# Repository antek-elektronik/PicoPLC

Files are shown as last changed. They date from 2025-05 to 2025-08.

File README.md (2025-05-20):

# picoPLC

Work in progress! 

This is 'industriual' adaptation for raspberry pi pico 2W. This is a hobby project developed by me (AntekElektronik) with no plans for building it (yet). 

## features 

This device features a 8 optotransistor 24V inputs, 4 10A 230V relay outputs and 4 transistor outputs latching to ground. The device is powered by 24V external power supply and has 24V -> 5V switching power regulator onboard (the rpi pico 2w takes care of regulating 3.3V). 

## wireles connectivity

I am aware that rpi pico's wireless features won't work enclosed inside a metal case. I plan on changing to esp32 with external antenna in future. This project could be used as a base for mainstream microcontroller based PLC controllers

## software

for the time of writing this, I do not have any software written. First stage would be a micropython file with predefined variables and functions for basic I/O operations on picoPLC platform, the rest would have to be written in micropython. 

I plan to use an existng project like openPLC, find something similar or write from scratch a program for executing ladder logic or function blocks.

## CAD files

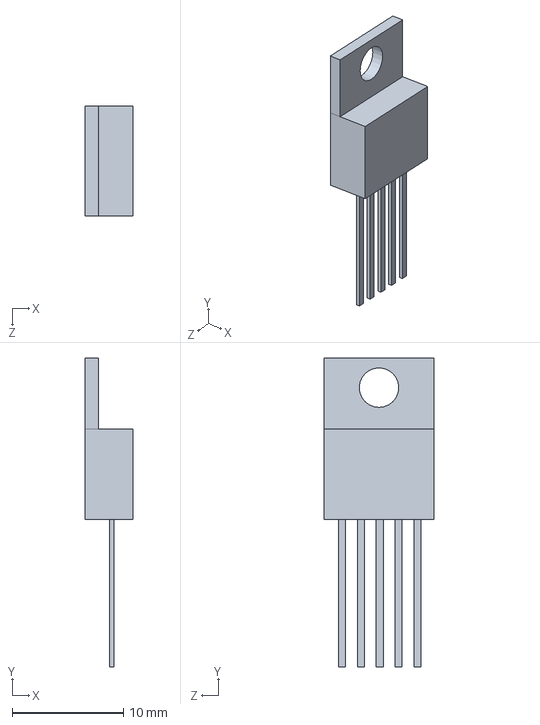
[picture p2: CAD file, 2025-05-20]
Hardware/CPU/lm 2578.SLDPRT
4.32 x 27.8 x 9.91 mm

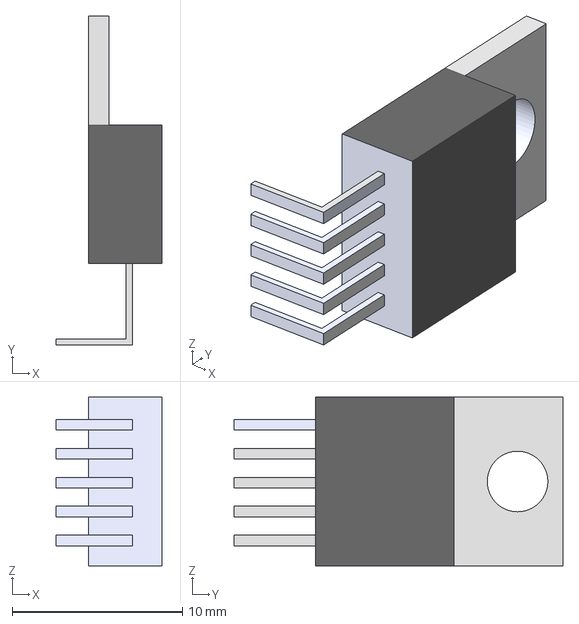
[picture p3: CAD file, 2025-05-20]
Hardware/CPU/lm 2578 - Part 1.step
6.22 x 19.3 x 9.91 mm

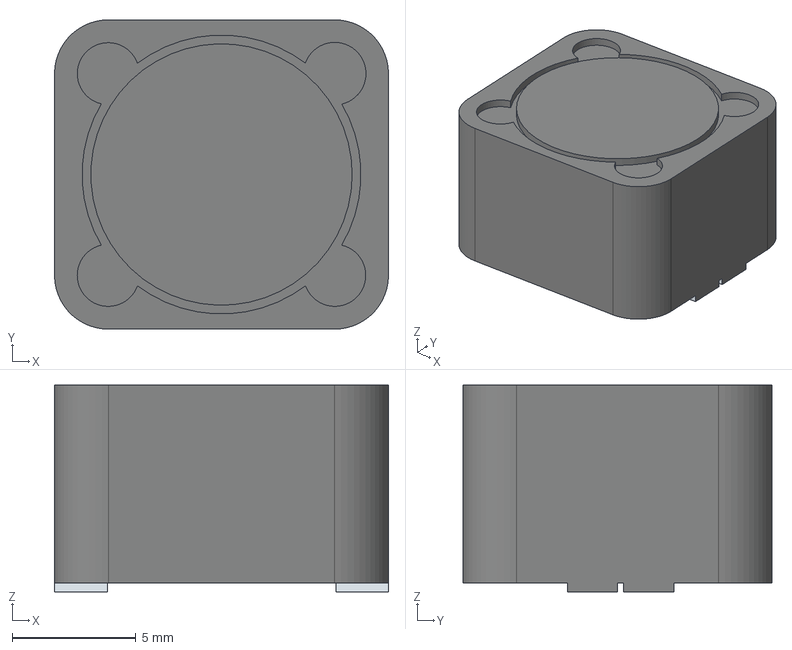
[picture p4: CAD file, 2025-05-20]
Hardware/CPU/DRQ127.step
13.5 x 12.5 x 8.36 mm

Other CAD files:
Hardware/CPU/DRQ127.sldprt
Hardware/CPU/DRQ127.stl
Hardware/CPU/lm 2578 - Part 1.iges
Hardware/CPU/lm 2578 - Part 1.sldprt
Hardware/CPU/lm 2578 - Part 1.stl
Hardware/CPU/lm 2578.stl

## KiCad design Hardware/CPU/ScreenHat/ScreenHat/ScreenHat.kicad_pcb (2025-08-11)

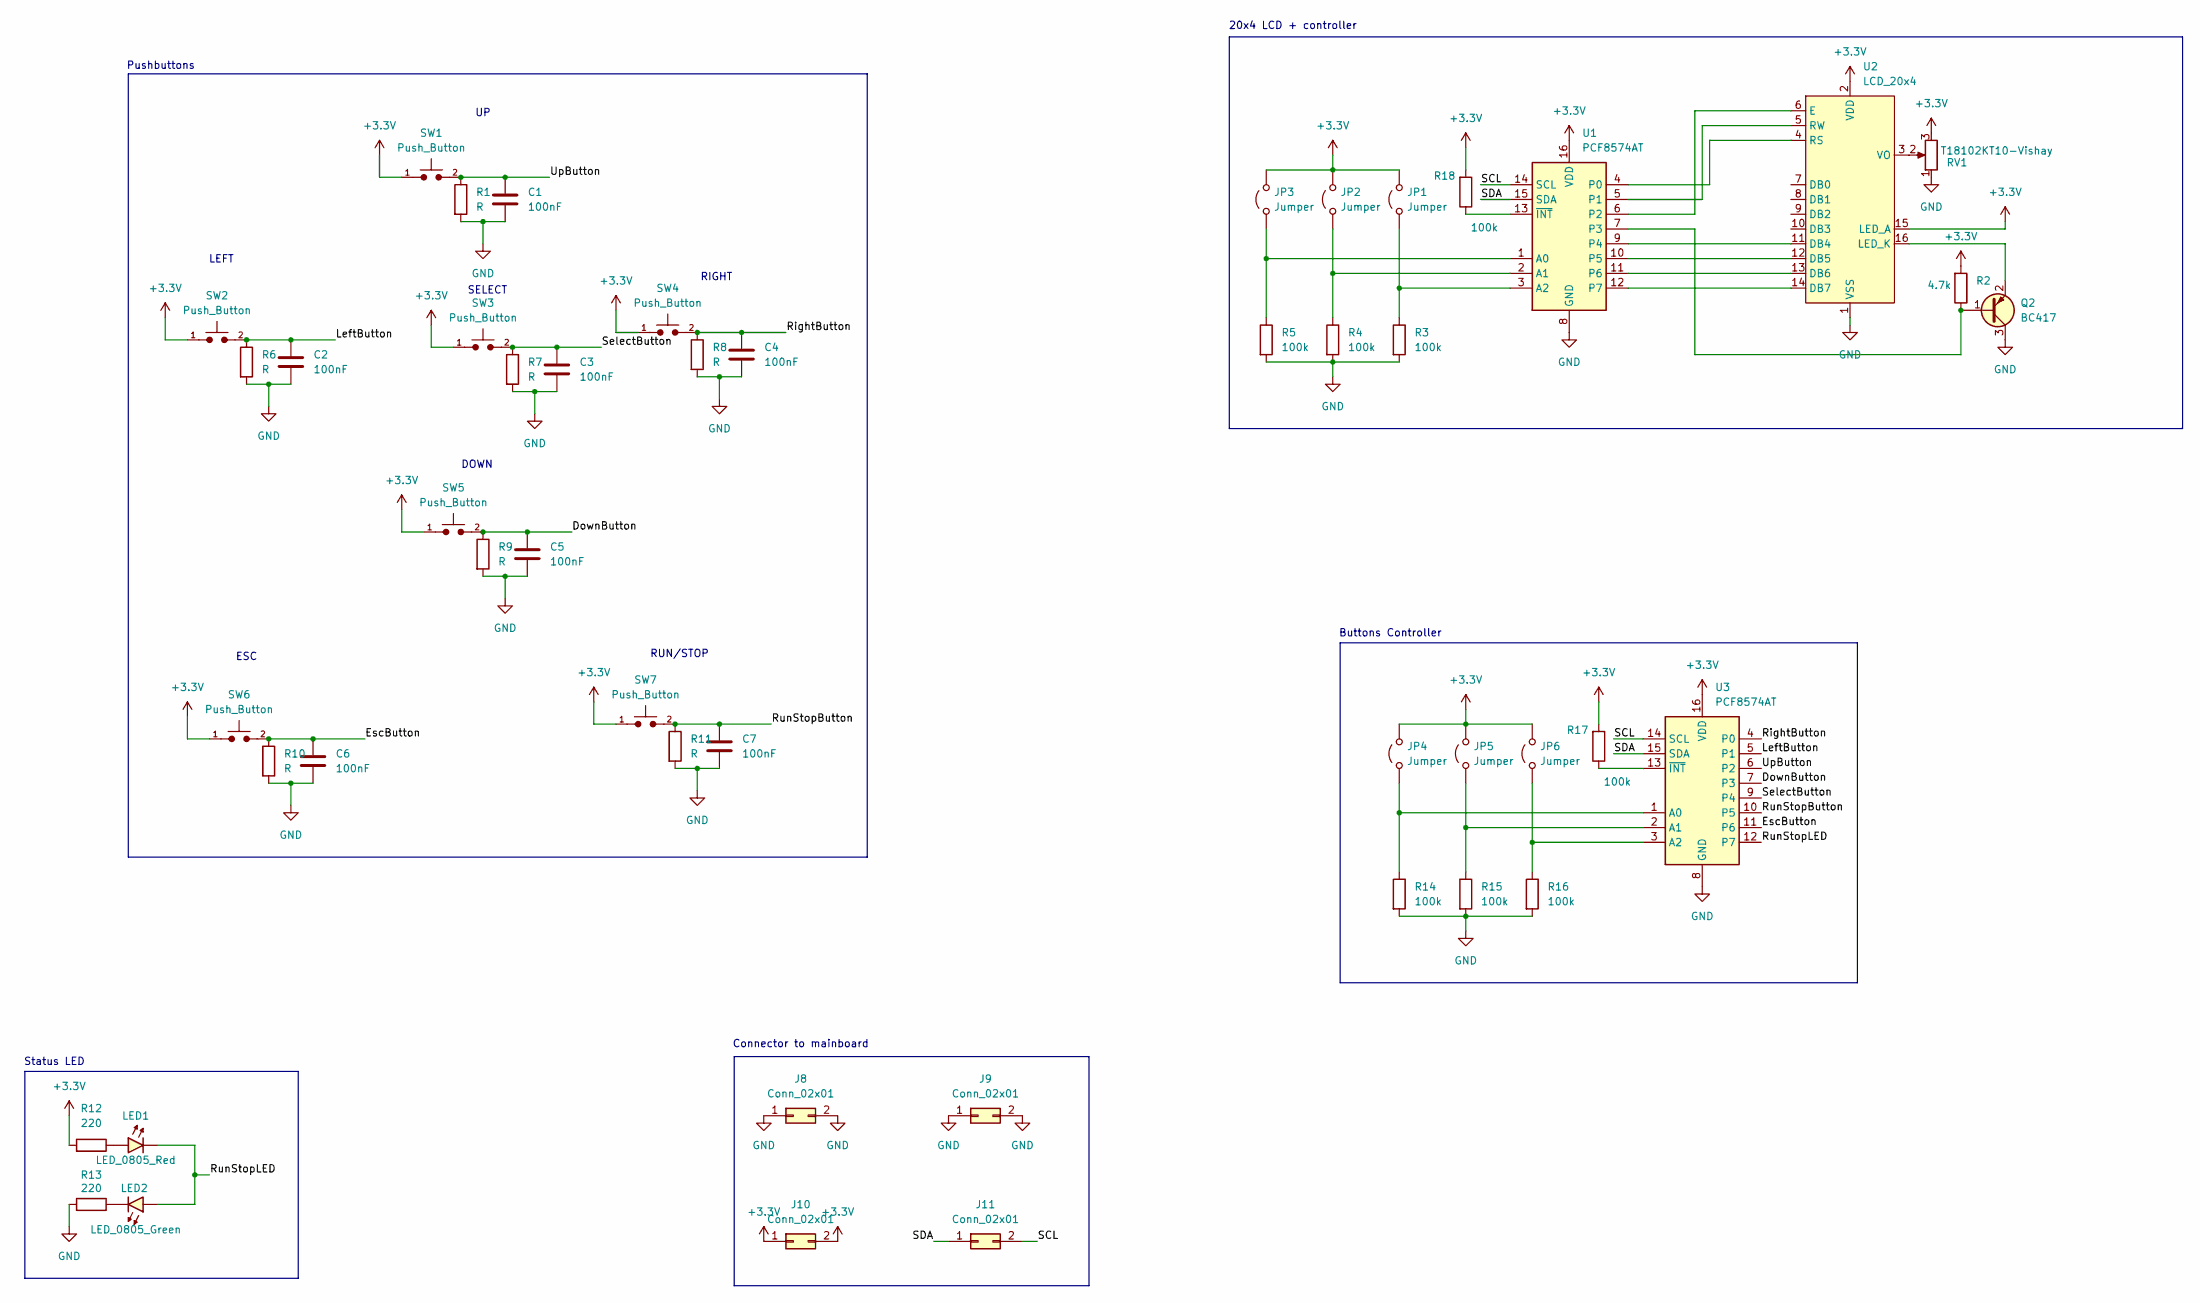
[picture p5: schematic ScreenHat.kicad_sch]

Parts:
C1, C2, C3, C4, C5, C6, C7: 100nF; C_0805_2012Metric_Pad1.18x1.45mm_HandSolder
J8, J9, J10, J11: Conn_02x01; PinHeader_2x01_P2.54mm_Vertical
JP1, JP2, JP3, JP4, JP5, JP6: Jumper; SolderJumper-2_P1.3mm_Open_RoundedPad1.0x1.5mm
LED1: LED_0805_Red; LED_0805_2012Metric
LED2: LED_0805_Green; LED_0805_2012Metric
Q2: BC417; SOT-23
R1, R6, R7, R8, R9, R10, R11: R; R_0805_2012Metric_Pad1.15x1.40mm_HandSolder
R2: 4.7k; R_0805_2012Metric
R3, R4, R5, R14, R15, R16: 100k; R_0805_2012Metric_Pad1.15x1.40mm_HandSolder
R12, R13: 220; R_0805_2012Metric
R17, R18: 100k; R_0805_2012Metric
RV1: T18102KT10-Vishay; Potentiometer_Bourns_3009P_Horizontal
SW1, SW2, SW3, SW4, SW5, SW6, SW7: Push_Button; SW_SPST_Omron_B3FS-105xP
U1, U3: PCF8574AT; SOIC-16W_7.5x10.3mm_P1.27mm
U2: LCD_20x4; LCD-16X4

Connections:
+3.3V: J10.1, J10.2, JP1.2 (B), JP2.2 (B), JP3.2 (B), JP4.2 (B), JP5.2 (B), JP6.2 (B), R2.1, R12.1, R17.1, R18.1, RV1.3, SW1.1, SW2.1, SW3.1, SW4.1, SW5.1, SW6.1, SW7.1, U1.16 (VDD), U2.2 (VDD), U2.15 (LED_A), U3.16 (VDD)
/DownButton: C5.1, R9.1, SW5.2, U3.7 (P3)
/EscButton: C6.1, R10.1, SW6.2, U3.11 (P6)
/LeftButton: C2.1, R6.1, SW2.2, U3.5 (P1)
/RightButton: C4.1, R8.1, SW4.2, U3.4 (P0)
/RunStopButton: C7.1, R11.1, SW7.2, U3.10 (P5)
/RunStopLED: LED1.1 (K), LED2.2 (A), U3.12 (P7)
/SCL: J11.2, U1.14 (SCL), U3.14 (SCL)
/SDA: J11.1, U1.15 (SDA), U3.15 (SDA)
/SelectButton: C3.1, R7.1, SW3.2, U3.9 (P4)
/UpButton: C1.1, R1.1, SW1.2, U3.6 (P2)
GND: C1.2, C2.2, C3.2, C4.2, C5.2, C6.2, C7.2, J8.1, J8.2, J9.1, J9.2, Q2.3 (C), R1.2, R3.2, R4.2, R5.2, R6.2, R7.2, R8.2, R9.2, R10.2, R11.2, R13.1, R14.2, R15.2, R16.2, RV1.1, U1.8 (GND), U2.1 (VSS), U3.8 (GND)
unnamed: JP1.1 (A), R3.1, U1.3 (A2)
unnamed: JP2.1 (A), R4.1, U1.2 (A1)
unnamed: JP3.1 (A), R5.1, U1.1 (A0)
unnamed: JP4.1 (A), R14.1, U3.1 (A0)
unnamed: JP5.1 (A), R15.1, U3.2 (A1)
unnamed: JP6.1 (A), R16.1, U3.3 (A2)
unnamed: LED1.2 (A), R12.2
unnamed: LED2.1 (K), R13.2
unnamed: Q2.1 (B), R2.2, U1.7 (P3)
unnamed: Q2.2 (E), U2.16 (LED_K)
unnamed: U1.4 (P0), U2.4 (RS)
unnamed: U1.5 (P1), U2.5 (RW)
unnamed: U1.6 (P2), U2.6 (E)
unnamed: U1.9 (P4), U2.11 (DB4)
unnamed: U1.10 (P5), U2.12 (DB5)
unnamed: U1.11 (P6), U2.13 (DB6)
unnamed: U1.12 (P7), U2.14 (DB7)
unnamed: R18.2, U1.13 (~INT)
unnamed: RV1.2, U2.3 (VO)
unnamed: R17.2, U3.13 (~INT)

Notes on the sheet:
DOWN
20x4 LCD + controller
ESC
RIGHT
Connector to mainboard
LEFT
Buttons Controller
SELECT
Pushbuttons
RUN/STOP
Status LED

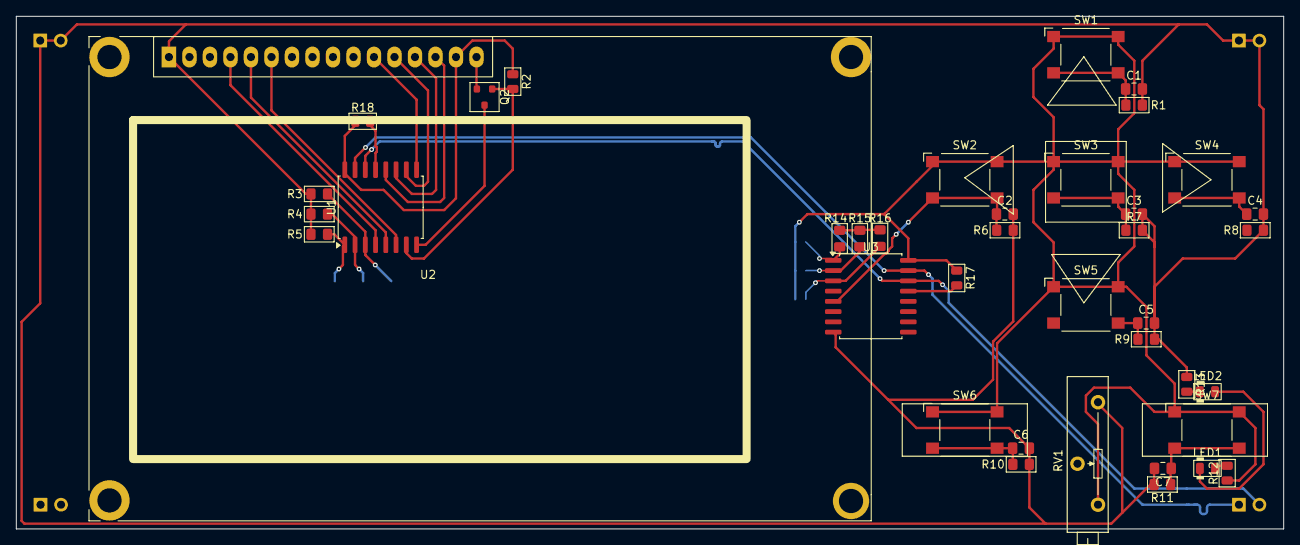
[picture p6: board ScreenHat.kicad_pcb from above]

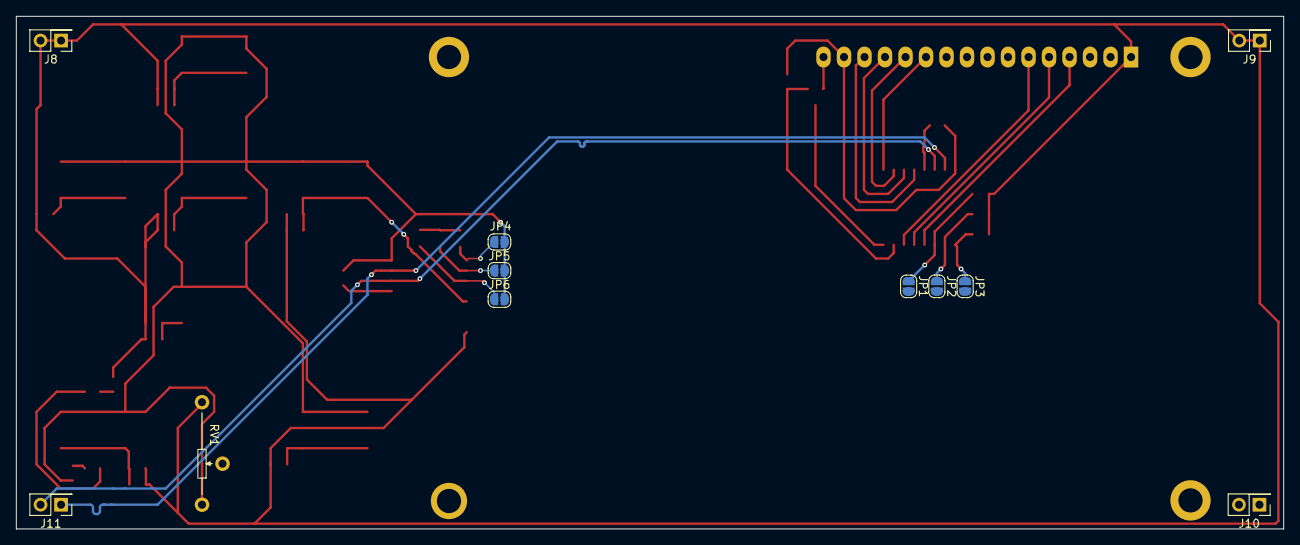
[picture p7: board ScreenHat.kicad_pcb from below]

Board: 2 copper layers, 157.0 x 63.5 mm, 49 parts (10 on the bottom side), 32 nets.

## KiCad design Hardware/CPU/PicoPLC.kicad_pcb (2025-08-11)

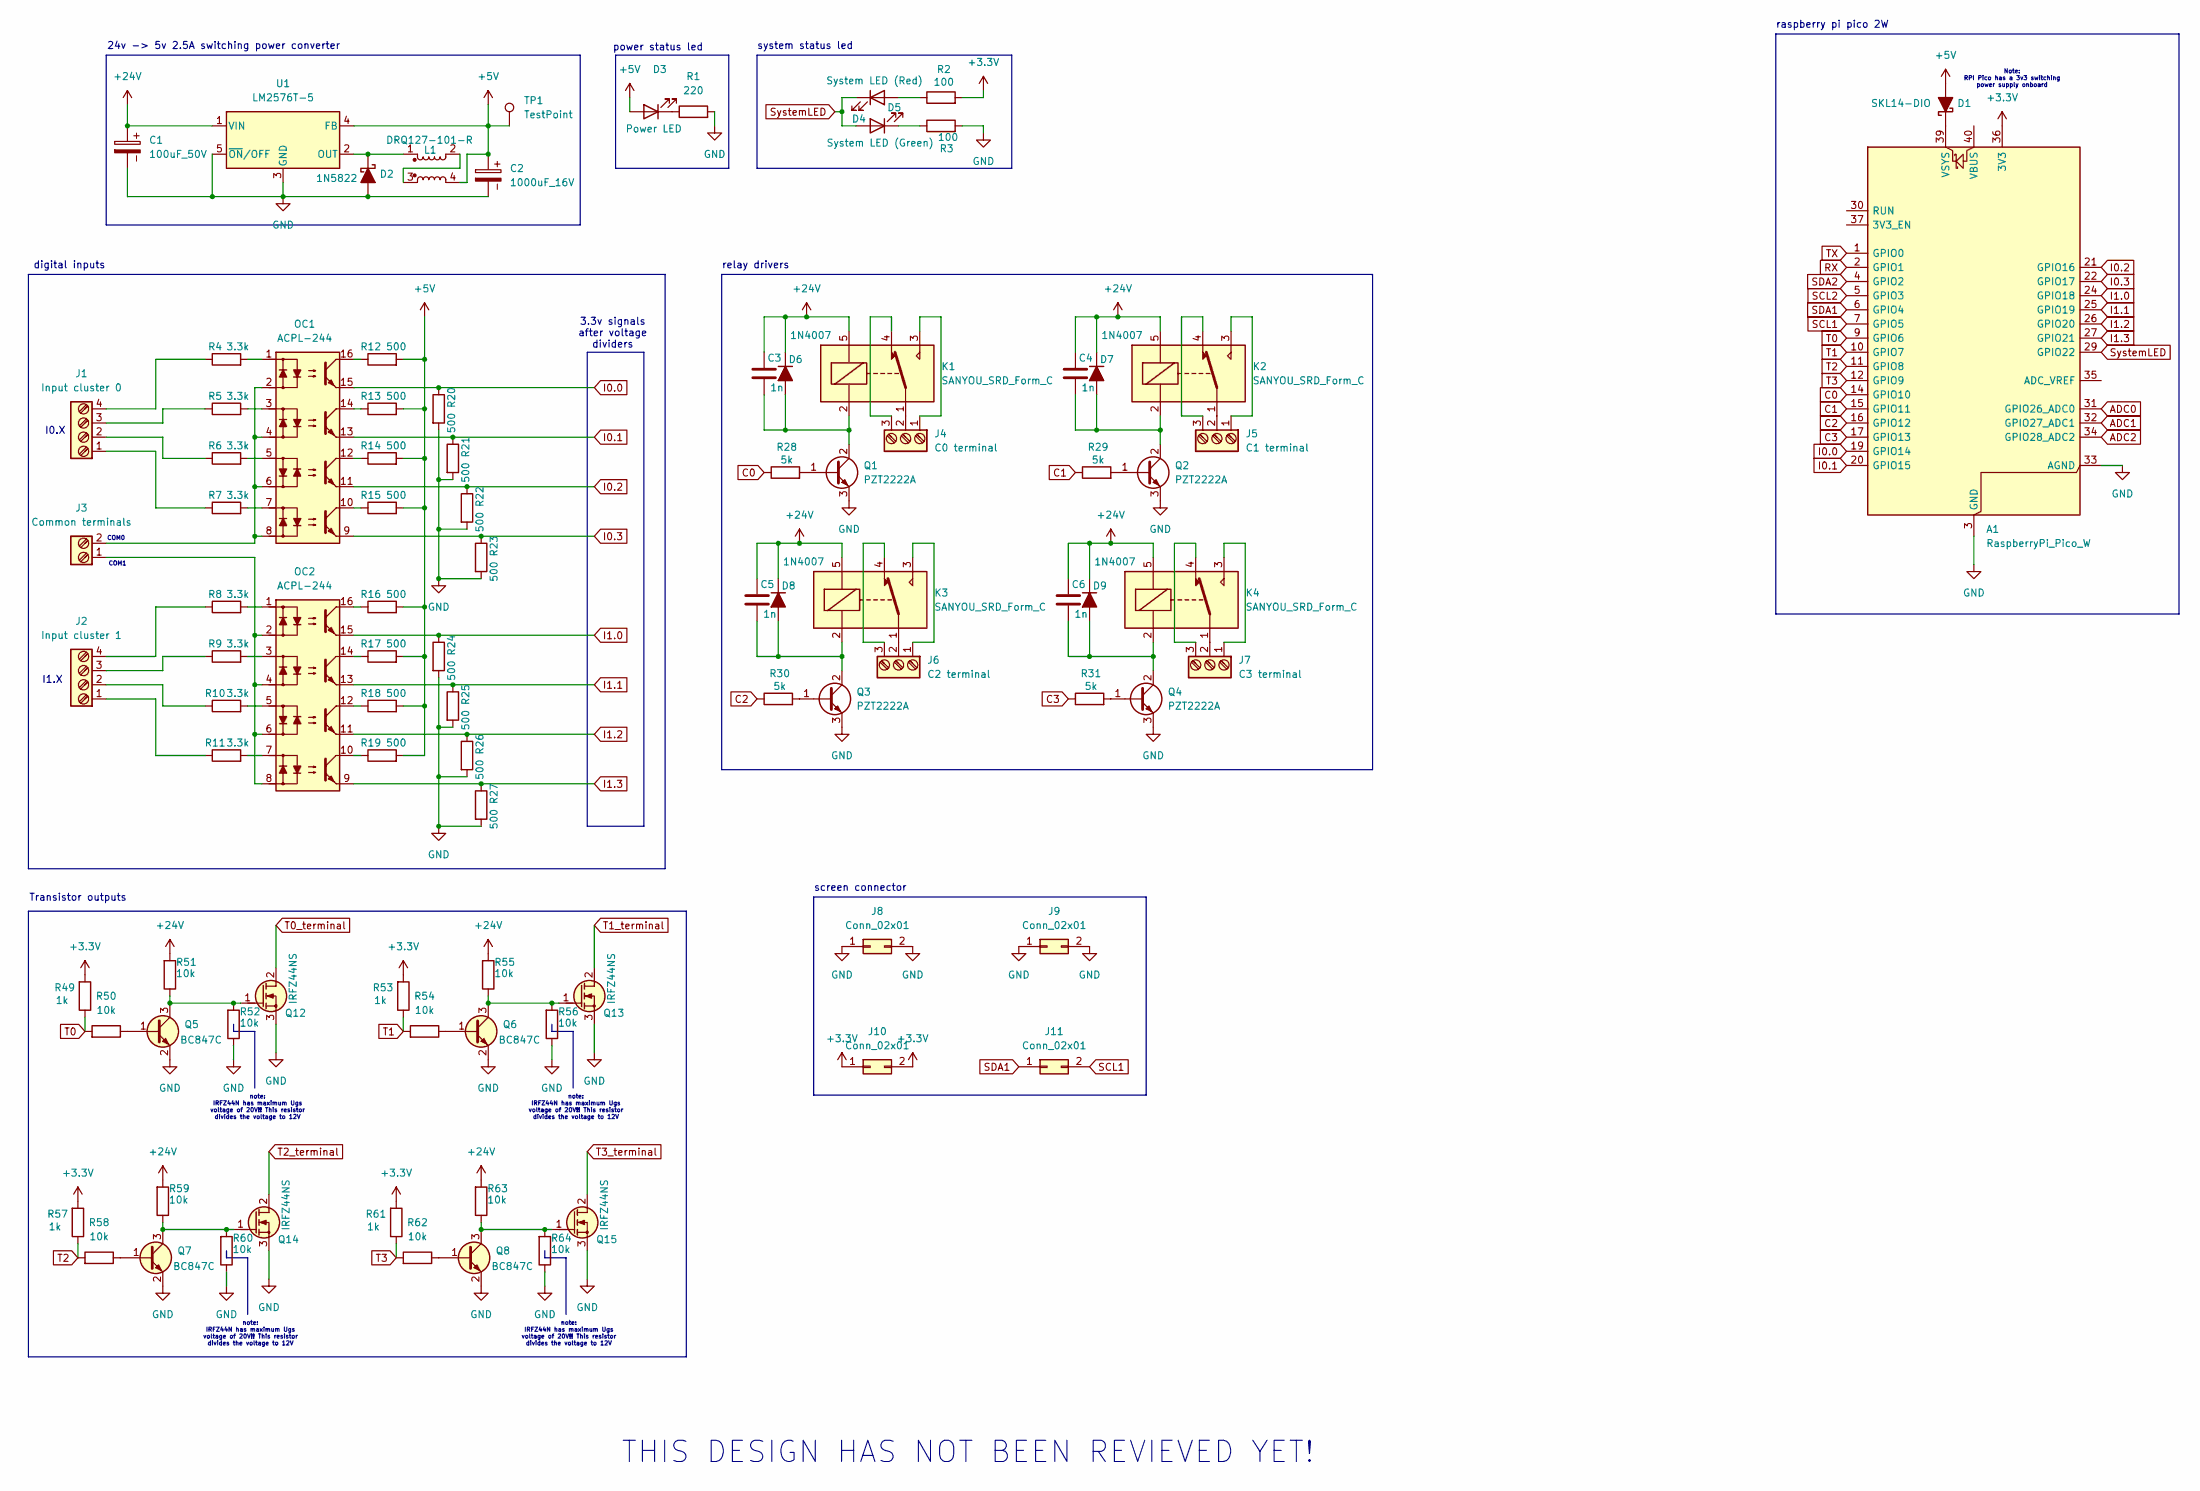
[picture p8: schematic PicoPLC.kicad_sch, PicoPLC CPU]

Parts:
A1: RaspberryPi_Pico_W; RaspberryPi_Pico_W_SMD_HandSolder
C1: 100uF_50V; CP_Radial_D8.0mm_P3.50mm
C2: 1000uF_16V; CP_Radial_D10.0mm_P5.00mm
C3, C4, C5, C6: 1n; C_0805_2012Metric_Pad1.18x1.45mm_HandSolder
D1: SKL14-DIO; D_SOD-123F
D2: 1N5822; D_DO-201AD_P12.70mm_Horizontal
D3: Power LED; LED_0805_2012Metric_Pad1.15x1.40mm_HandSolder
D4: System LED (Green); LED_0805_2012Metric_Pad1.15x1.40mm_HandSolder
D5: System LED (Red); LED_0805_2012Metric_Pad1.15x1.40mm_HandSolder
D6, D7, D8, D9: 1N4007; D_SOD-123
J1: Input cluster 0; TerminalBlock_Phoenix_PT-1,5-4-5.0-H_1x04_P5.00mm_Horizontal
J2: Input cluster 1; TerminalBlock_Phoenix_PT-1,5-4-5.0-H_1x04_P5.00mm_Horizontal
J3: Common terminals; TerminalBlock_Phoenix_PT-1,5-2-3.5-H_1x02_P3.50mm_Horizontal
J4: C0 terminal; TerminalBlock_Phoenix_PT-1,5-3-5.0-H_1x03_P5.00mm_Horizontal
J5: C1 terminal; TerminalBlock_Phoenix_PT-1,5-3-5.0-H_1x03_P5.00mm_Horizontal
J6: C2 terminal; TerminalBlock_Phoenix_PT-1,5-3-5.0-H_1x03_P5.00mm_Horizontal
J7: C3 terminal; TerminalBlock_Phoenix_PT-1,5-3-5.0-H_1x03_P5.00mm_Horizontal
J8: Conn_02x01; PinHeader_2x01_P2.54mm_Vertical
J9, J10, J11: Conn_02x01
K1, K2, K3, K4: SANYOU_SRD_Form_C; Relay_SPDT_SANYOU_SRD_Series_Form_C
L1: DRQ127-101-R; L_Bourns_SRF1260
OC1, OC2: ACPL-244; SO-16_5.3x10.2mm_P1.27mm
Q1, Q2, Q3, Q4: PZT2222A; SOT-223-3_TabPin2
Q5, Q6, Q7, Q8: BC847C; SOT-23
Q12, Q13, Q14, Q15: IRFZ44NS; TO-263-2
R1: 220; R_0805_2012Metric_Pad1.15x1.40mm_HandSolder
R2, R3: 100; R_0805_2012Metric_Pad1.15x1.40mm_HandSolder
R4, R5, R6, R7, R8, R9, R10, R11: 3.3k; R_0805_2012Metric_Pad1.15x1.40mm_HandSolder
R12, R13, R14, R15, R16, R17, R18, R19, R20, R21, R22, R23, R24, R25, R26, R27: 500; R_0805_2012Metric_Pad1.15x1.40mm_HandSolder
R28, R29, R30, R31: 5k; R_0805_2012Metric_Pad1.15x1.40mm_HandSolder
R49, R53, R57, R61: 1k; R_1806_4516Metric
R50, R51, R52, R54, R55, R56, R58, R59, R60, R62, R63, R64: 10k; R_1806_4516Metric
TP1: TestPoint; TestPoint_Pad_D2.0mm
U1: LM2576T-5; TO-220-5_Horizontal_TabDown

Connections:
+3.3V: A1.36 (3V3), J10.1, J10.2, R2.2, R49.1, R53.1, R57.1, R61.1
+5V: C2.1, D1.2 (A), D3.2 (A), L1.4, R12.2, R13.2, R14.2, R15.2, R16.2, R17.2, R18.2, R19.2, TP1.1, U1.4 (FB)
+24V: C1.1, C3.1, C4.1, C5.1, C6.1, D6.1 (K), D7.1 (K), D8.1 (K), D9.1 (K), K1.5, K2.5, K3.5, K4.5, R51.1, R55.1, R59.1, R63.1, U1.1 (VIN)
ADC0: A1.31 (GPIO26_ADC0)
ADC1: A1.32 (GPIO27_ADC1)
ADC2: A1.34 (GPIO28_ADC2)
C0: A1.14 (GPIO10), R28.1
C1: A1.15 (GPIO11), R29.1
C2: A1.16 (GPIO12), R30.1
C3: A1.17 (GPIO13), R31.1
GND: A1.3 (GND), A1.8 (GND), A1.13 (GND), A1.18 (GND), A1.23 (GND), A1.28 (GND), A1.33 (AGND), A1.38 (GND), C1.2, C2.2, D2.2 (A), J8.1, J8.2, J9.1, J9.2, Q1.3 (E), Q2.3 (E), Q3.3 (E), Q4.3 (E), Q5.2 (E), Q6.2 (E), Q7.2 (E), Q8.2 (E), Q12.3 (S), Q13.3 (S), Q14.3 (S), Q15.3 (S), R1.2, R3.2, R20.2, R21.2, R22.2, R23.2, R24.2, R25.2, R26.2, R27.2, R52.2, R56.2, R60.2, R64.2, U1.3 (GND), U1.5 (~ON/OFF)
I0.0: A1.19 (GPIO14), OC1.15, R20.1
I0.1: A1.20 (GPIO15), OC1.13, R21.1
I0.2: A1.21 (GPIO16), OC1.11, R22.1
I0.3: A1.22 (GPIO17), OC1.9, R23.1
I1.0: A1.24 (GPIO18), OC2.15, R24.1
I1.1: A1.25 (GPIO19), OC2.13, R25.1
I1.2: A1.26 (GPIO20), OC2.11, R26.1
I1.3: A1.27 (GPIO21), OC2.9, R27.1
unnamed: A1.39 (VSYS), D1.1 (K)
unnamed: D2.1 (K), L1.1, U1.2 (OUT)
unnamed: D3.1 (K), R1.1
unnamed: D4.1 (K), R3.1
unnamed: D5.2 (A), R2.1
unnamed: C3.2, D6.2 (A), K1.2, Q1.2 (C)
unnamed: C4.2, D7.2 (A), K2.2, Q2.2 (C)
unnamed: C5.2, D8.2 (A), K3.2, Q3.2 (C)
unnamed: C6.2, D9.2 (A), K4.2, Q4.2 (C)
unnamed: J1.1, R7.1
unnamed: J1.2, R6.1
unnamed: J1.3, R5.1
unnamed: J1.4, R4.1
unnamed: J2.1, R11.1
unnamed: J2.2, R10.1
unnamed: J2.3, R9.1
unnamed: J2.4, R8.1
unnamed: J3.1, OC2.2, OC2.4, OC2.6, OC2.8
unnamed: J3.2, OC1.2, OC1.4, OC1.6, OC1.8
unnamed: J4.1, K1.3
unnamed: J4.2, K1.1
unnamed: J4.3, K1.4
unnamed: J5.1, K2.3
unnamed: J5.2, K2.1
unnamed: J5.3, K2.4
unnamed: J6.1, K3.3
unnamed: J6.2, K3.1
unnamed: J6.3, K3.4
unnamed: J7.1, K4.3
unnamed: J7.2, K4.1
unnamed: J7.3, K4.4
unnamed: L1.2, L1.3
unnamed: OC1.1, R4.2
unnamed: OC1.3, R5.2
unnamed: OC1.5, R6.2
unnamed: OC1.7, R7.2
unnamed: OC1.10, R15.1
unnamed: OC1.12, R14.1
unnamed: OC1.14, R13.1
unnamed: OC1.16, R12.1
unnamed: OC2.1, R8.2
unnamed: OC2.3, R9.2
unnamed: OC2.5, R10.2
unnamed: OC2.7, R11.2
unnamed: OC2.10, R19.1
unnamed: OC2.12, R18.1
unnamed: OC2.14, R17.1
unnamed: OC2.16, R16.1
unnamed: Q1.1 (B), R28.2
unnamed: Q2.1 (B), R29.2
unnamed: Q3.1 (B), R30.2
unnamed: Q4.1 (B), R31.2
unnamed: Q5.1 (B), R50.2
unnamed: Q6.1 (B), R54.2
unnamed: Q7.1 (B), R58.2
unnamed: Q8.1 (B), R62.2
unnamed: Q5.3 (C), Q12.1 (G), R51.2, R52.1
unnamed: Q6.3 (C), Q13.1 (G), R55.2, R56.1
unnamed: Q7.3 (C), Q14.1 (G), R59.2, R60.1
unnamed: Q8.3 (C), Q15.1 (G), R63.2, R64.1
RX: A1.2 (GPIO1)
SCL1: A1.7 (GPIO5), J11.2
SCL2: A1.5 (GPIO3)
SDA1: A1.6 (GPIO4), J11.1
SDA2: A1.4 (GPIO2)
SystemLED: A1.29 (GPIO22), D4.2 (A), D5.1 (K)
T0: A1.9 (GPIO6), R49.2, R50.1
T0_terminal: Q12.2 (D)
T1: A1.10 (GPIO7), R53.2, R54.1
T1_terminal: Q13.2 (D)
T2: A1.11 (GPIO8), R57.2, R58.1
T2_terminal: Q14.2 (D)
T3: A1.12 (GPIO9), R61.2, R62.1
T3_terminal: Q15.2 (D)
TX: A1.1 (GPIO0)

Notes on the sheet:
Transistor outputs
relay drivers
note: IRFZ44N has maximum Ugs voltage of 20V!! This resistor divides the voltage to 12V
3.3v signals after voltage dividers
digital inputs
24v -> 5v 2.5A switching power converter
I1.X
I0.X
COM1
screen connector
system status led
COM0
THIS DESIGN HAS NOT BEEN REVIEVED YET!
power status led
raspberry pi pico 2W
Note: RPI Pico has a 3v3 switching power supply onboard

Board: 2 copper layers, 92 parts (0 on the bottom side), 81 nets, no tracks yet.

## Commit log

2025-05-20 added files
    added files
    [DRQ127.sldprt, DRQ127.step, DRQ127.stl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]
2025-06-27 working on screen capabilities
    [PicoPLC.kicad_sch, ScreenHat.kicad_pcb, ScreenHat.kicad_sch]
2025-08-11 finished ScreenHat Schematics
    [PicoPLC.kicad_pcb, ScreenHat.kicad_sch]
2025-08-11 started designing ScreenHat Board
    [ScreenHat.kicad_pcb]
